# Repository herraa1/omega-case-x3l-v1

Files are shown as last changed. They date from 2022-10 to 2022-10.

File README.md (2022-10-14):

# Omega Home Computer XXXL Acrylic Case

Acrylic case of size XXXL, from now on X3L, for the [Omega Home Computer](https://github.com/skiselev/omega).

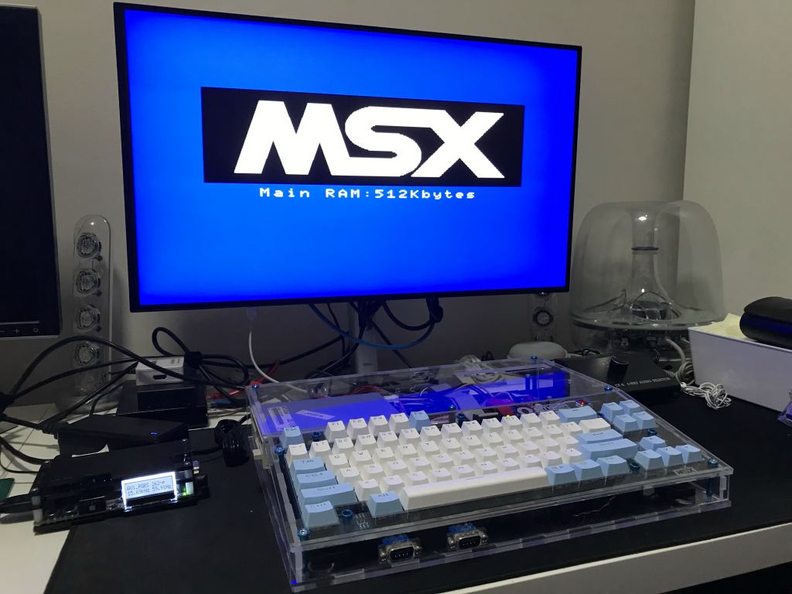
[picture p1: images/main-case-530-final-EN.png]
[](images/main-case-530-final-EN.png)

## Introduction

This is a new acrylic case design[^1] for the Omega Home Computer based on [Capsule5000 XL version](https://github.com/msx-solis/OMEGA-long-case/tree/main/Capsule_XL_current_version), specifically on the Omega-Eco2_SME_51mm_simple_22_09_2021_slot_trasero.dxf design, adding the following extra features:

* the [dc-adapter 1.5-1.6b](https://msxmakers.design.blog/proyectos/omega-home-computer/mini-fuente-dc-dc/) can be installed in the ["inverted-power-barrel"](https://msxmakers.design.blog/proyectos/omega-home-computer/mini-fuente-dc-dc/#barril) configuration without colliding with the floppy disk drive
* the dc-adapter can also be installed in alternate locations using a panel mount power connector (or even the ["anchored-switch"](https://msxmakers.design.blog/proyectos/omega-home-computer/mini-fuente-dc-dc/#anclado) configuration)
* a bigger cutout allows to accomodate the larger rectangular form of the [power SPDT switch 3-pin copper](https://www.aliexpress.com/item/1005001667810183.html) used in the dc-adapter 1.5-1.6b kit
* taller ESR capacitors can be used, with or sans the [multimedia hat](https://msxmakersdesign.files.wordpress.com/2021/09/mmedia_hat_v1.jpg), without colliding with the floppy disk drive
* extra space bellow the floppy disk drive allows a taller and full length heat sink to be installed on top of the VDP if required
* new vent holes below the motherboard VDP footprint are provided for better air flow
* the floppy disk tray is secured to prevent vertical movement irrespective of the floppy disk drive height
* the reset switch has been moved to the keyboard plate, in line with most MSX computers equipped with a reset switch
* all connectors are labeled (using the [MSX font](https://www.msx.org/wiki/MSX_font))[^2]
* the Omega and MSX logos are also incorporated
* (need to be tested) the floppy disk tray has been re-designed trying to remain compatible with the F4/FMPAC v2 hat
* (need to be tested) enough clearance has been kept trying to remain compatible with the O4MEGA v2 hat
* a companion tray has been designed to ease the placement of the dc-adapter 1.5-1.6b (which lacks screw holes on the PCB)

## Dimensions

Dimensions of Capsule5000 XL case

* width  : 360.0 mm
* height :  60.6 mm
* depth  : 287.8 mm

Dimensions of X3L case

* width  : 360.0 mm
* height :  60.6 mm
* depth  : 312.0 mm (+24.2 mm)

## Status

* The case has been built and is fully functional
* The F4/FMPAC v2 compatibility remains untested until a hat is available for testing
* The O4MEGA v2 compatibility remains untested until a hat is available for testing

## Documentation

[Build instructions](Build.md)

[^1]: The case was designed using the [LibreCAD](https://librecad.org/) CAD application.  
[^2]: This [MSX font in TTF format](http://www.ateijelo.com/blog/2016/09/13/making-an-msx-font) was [converted to LFF](https://github.com/LibreCAD/LibreCAD/tree/master/tools/ttf2lff) for use within LibreCAD.

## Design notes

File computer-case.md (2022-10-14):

# Build Instructions for the X3L Computer Case

This document describes how to assemble a X3L case for the Omega Home Computer.

## Bill of Materials (BoM)

### Acrylic parts

#### Computer case (4mm thickness)

The [X3L Computer case](omega-case-x3l-v1-case-with-rear-slot-4mm+ready-to-lasercut-msx-font-normal-final.dxf) for the Omega Home Computer is made up of seven panels:  
* Rear panel (where all the rear connectors are placed)
  * Dimensions: 360.00mm x 60.60mm x 4mm
* Left panel (where the floppy disk drive front is located)
  * Dimensions: 303.95mm x 60.60mm
* Right panel (where the audio/video knobs are attached)
  * Dimensions: 303.95mm x 60.60mm
* Front panel (where the joystick ports are secured)
  * Dimensions: 360.00mm x 28.96mm
* Bottom panel (where the motherboard sits)
  * Dimensions: 360.00mm x 312.00mm
* Top panel (where the top slot is located)
  * Dimensions: 360.00mm x 165.76mm
* Keyboard panel (where the keyboard is attached)
  * Dimensions: 360.00mm x 148.92mm

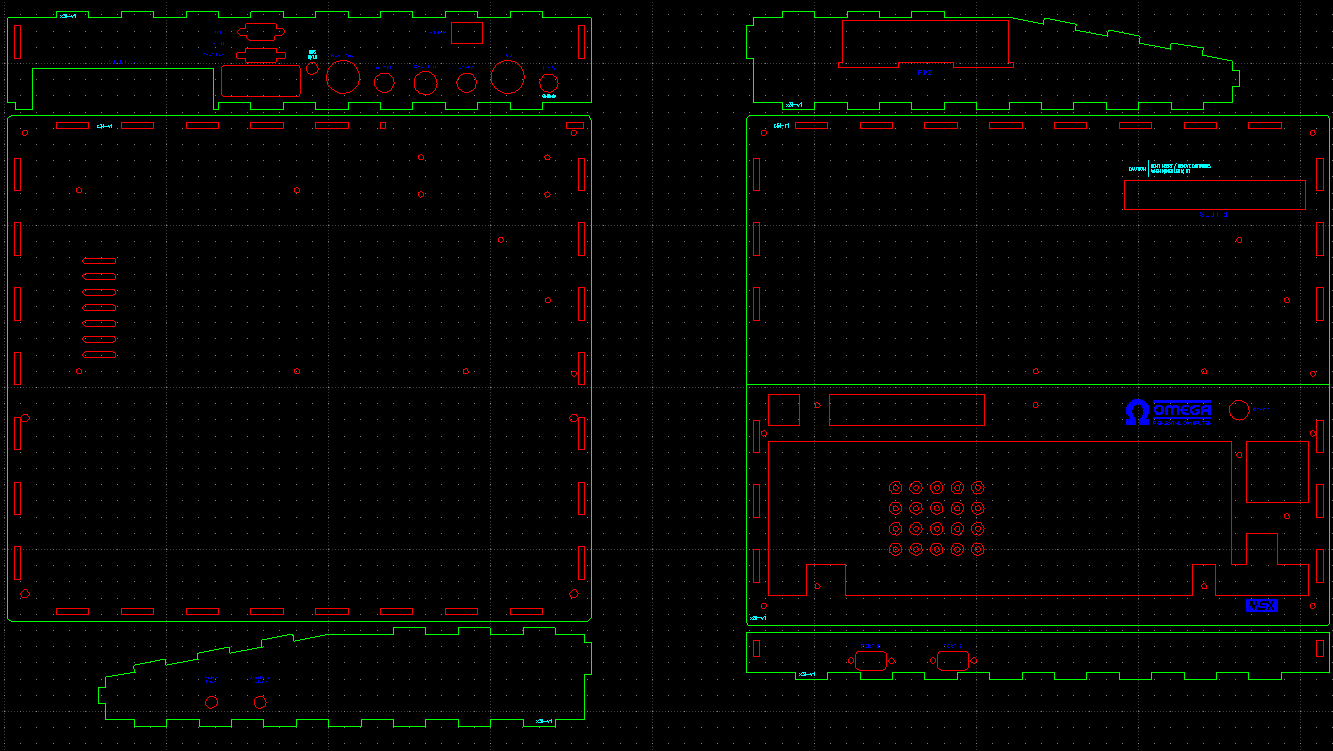
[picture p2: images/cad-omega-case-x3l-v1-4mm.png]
[](images/cad-omega-case-x3l-v1-4mm.png)

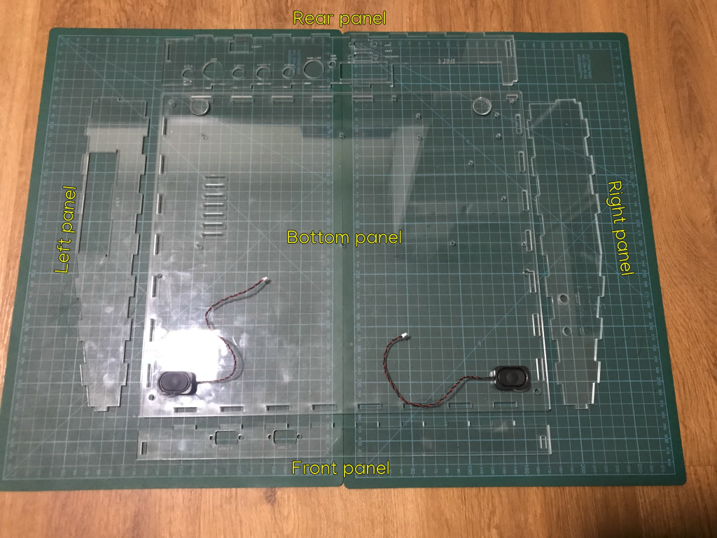
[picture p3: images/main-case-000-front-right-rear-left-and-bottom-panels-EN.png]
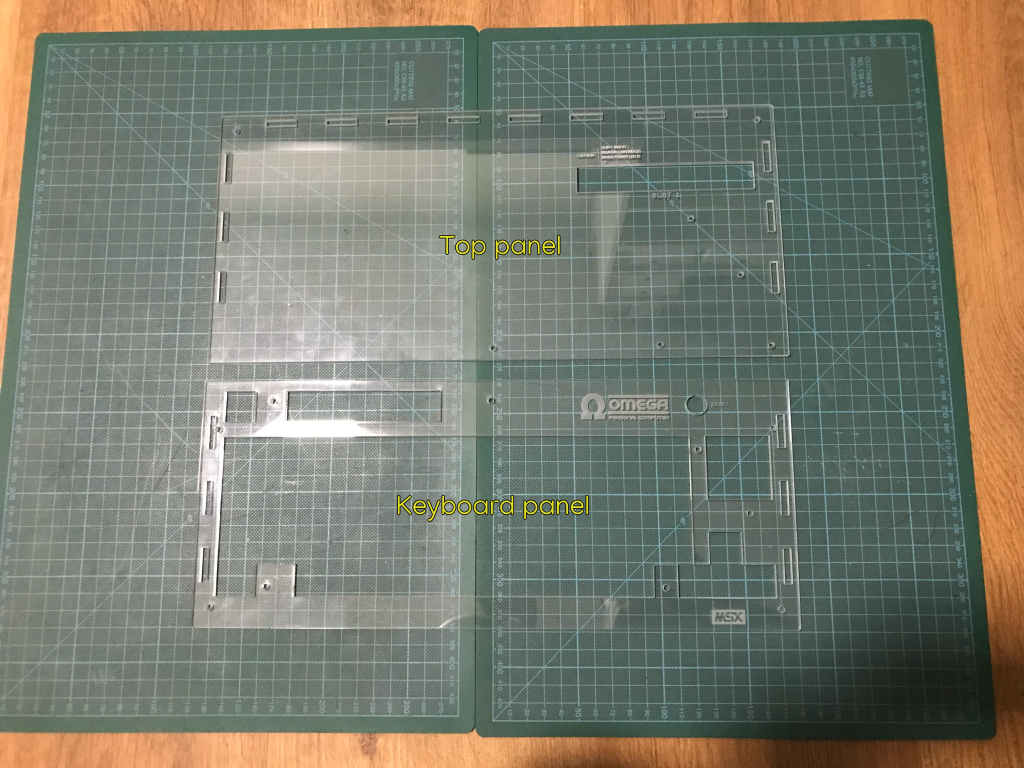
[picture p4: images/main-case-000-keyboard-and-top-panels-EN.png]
[](images/main-case-000-front-right-rear-left-and-bottom-panels-EN.png) [](images/main-case-000-keyboard-and-top-panels-EN.png)

### Laser cutting

The Omega Computer X3L case CAD design requires a 4mm thick acrylic sheet and has 20 layers that must be processed in this order:

| Layer Name | Color | Operation | Required | Comment | Processing Order |
|:---:|---|:---:|---|:---:|:---:|
| engraving-raster | blue  |  engrave  | recommended | Rasterized fonts | 1 |
| engraving-raster-msxlogo | blue  |  engrave  | recommended | MSX logo | 2 |
| engraving-vector | cyan  |  engrave  | recommended | Vectorized fonts | 3 |
| case-top-keyb-int-1 | red | cut | mandatory | internal cuts for spacers | 4 |
| case-top-keyb-int-2 | red | cut | mandatory | external cuts for spacers | 5 |
| case-top-keyb-int-3 | red | cut | mandatory | internal cuts for keyboard plate | 6 |
| *-int (7 layers) | red | cut | mandatory | internal cuts | 7 |
| *-ext (7 layers) | green | cut | mandatory | external cuts | 8 |

### Tools

I used the following tools to build the Omega computer case:

* torx screwdriver (8x60)
* philips screwdriver
* wire stripper & cutter (Stanley FatMax)
* soldering station (Yihua 908D)
* hot air gun
* JST1.25 crimping tool (IWS-2820M)
* XH2.54 crimping tool (SN-01BM)
* Dupont crimping tool (SN-28B)
* Ferrule crimping tool (HSC8 6-4)
* portable drilling machine with countersink 20.5mm drill bit for acrylic

### Mechanical parts

| **item** | **count** | **style** | **material** | **color** | **length (mm)** | **link** |
|---|---|---|---|---|---|---|
| 12mm mini push button switch, momentary, 2 pin | 1 | momentary | metal | red | 12 | [aliexpress](https://www.aliexpress.com/item/32992880809.html) |
| 18AWG silicone wire black | 1 | flexible | silicone,copper | black | 300 | [aliexpress](https://www.aliexpress.com/item/4001048052736.html) |
| 18AWG silicone wire red | 2 | flexible | silicone,copper | red | 300 | [aliexpress](https://www.aliexpress.com/item/4001048052736.html) |
| 20AWG silicone wire black | 1 | flexible | silicone,copper | black | 100 | [aliexpress](https://www.aliexpress.com/item/4001048052736.html) |
| 20AWG silicone wire red | 1 | flexible | silicone,copper | red | 100 | [aliexpress](https://www.aliexpress.com/item/4001048052736.html) |
| 22AWG silicone wire black | 3 | flexible | silicone,copper | black | 400 | [aliexpress](https://www.aliexpress.com/item/4001048052736.html) |
| 22AWG silicone wire blue | 3 | flexible | silicone,copper | blue | 400 | [aliexpress](https://www.aliexpress.com/item/4001048052736.html) |
| 22AWG silicone wire red | 3 | flexible | silicone,copper | red | 400 | [aliexpress](https://www.aliexpress.com/item/4001048052736.html) |
| 22AWG silicone wire yellow | 1 | flexible | silicone,copper | yellow | 400 | [aliexpress](https://www.aliexpress.com/item/4001048052736.html) |
| 24AWG silicone black wire | 1 | flexible | silicone,copper | black | 180 | [aliexpress](https://www.aliexpress.com/item/4001048052736.html) |
| 24AWG silicone blue wire | 1 | flexible | silicone,copper | blue | 350 | [aliexpress](https://www.aliexpress.com/item/4001048052736.html) |
| 24AWG silicone green wire | 1 | flexible | silicone,copper | green | 250 | [aliexpress](https://www.aliexpress.com/item/4001048052736.html) |
| 24AWG silicone red wire | 1 | flexible | silicone,copper | red | 180 | [aliexpress](https://www.aliexpress.com/item/4001048052736.html) |
| 24AWG silicone white wire | 1 | flexible | silicone,copper | white | 600 | [aliexpress](https://www.aliexpress.com/item/4001048052736.html) |
| 26AWG silicone wire black | 1 | flexible | silicone,copper | black | 400 | [aliexpress](https://www.aliexpress.com/item/4001048052736.html) |
| 26AWG silicone wire red | 1 | flexible | silicone,copper | red | 450 | [aliexpress](https://www.aliexpress.com/item/4001048052736.html) |
| 28AWG silicone wire black | 1 | flexible | silicone,copper | black | 250 | [aliexpress](https://www.aliexpress.com/item/4001048052736.html) |
| 28AWG silicone wire black | 1 | flexible | silicone,copper | black | 120 | [aliexpress](https://www.aliexpress.com/item/4001048052736.html) |
| 28AWG silicone wire red | 1 | flexible | silicone,copper | red | 370 | [aliexpress](https://www.aliexpress.com/item/4001048052736.html) |
| 28cm Male jack cable adapter plug 5.5 * 2.1mm 18 AWG | 1 | cable | plastic,copper  | red,black | 280 | [aliexpress](https://www.aliexpress.com/item/4000353876165.html) |
| 4 Ohm 3W mini speakers | 2 | mini | plastic | black | 20 | [aliexpress](https://www.aliexpress.com/item/4001125341633.html) |
| 4-pin floppy power cable 30cm | 1 | 4-pin | plastic,copper  | red,black,yellow | 300 | [aliexpress](https://www.aliexpress.com/item/1005002496348255.html) |
| 5.5mm x 2.1mm DC power jack socket female panel mount barrel connector 11mm | 1 | 5.5x2.1 | metal | metal | 16 | [aliexpress](https://www.aliexpress.com/item/33000366972.html) |
| Blu Tack reusable adhesive putty | 1 | adhesive | putty | blue | 0 | [aliexpress](https://www.aliexpress.com/item/1005004208353049.html) |
| Dupont female pin | 6 | female | copper | metal | 12 | [aliexpress](https://www.aliexpress.com/item/1005001489545874.html) |
| Dupont female sleeve 2-pin | 3 | sleeve | plastic | black | 14 | [aliexpress](https://www.aliexpress.com/item/1005001489545874.html) |
| E0508 bootlace ferrules 0.5mm2 white | 3 | bootlace | plastic,copper  | white | 14 | [aliexpress](https://www.aliexpress.com/item/4000580009797.html) |
| Heat shrink tube black | 1 | tube | plastic | black | 80 | [aliexpress](https://www.aliexpress.com/item/1005004519062414.html) |
| Heat shrink tube blue | 1 | tube | plastic | blue | 20 | [aliexpress](https://www.aliexpress.com/item/1005004519062414.html) |
| Heat shrink tube green | 1 | tube | plastic | blue | 20 | [aliexpress](https://www.aliexpress.com/item/1005004519062414.html) |
| Heat shrink tube red | 1 | tube | plastic | red | 70 | [aliexpress](https://www.aliexpress.com/item/1005004519062414.html) |
| JST 1.25 Male 2-pin plug with wire 15cm 28awg | 2 | male,cable | plastic,copper  | red,black | 150 | [aliexpress](https://www.aliexpress.com/item/4000777530145.html) |
| JST1.25 2-pin male plug | 2 | male | plastic | white | 0 | [aliexpress](https://www.aliexpress.com/item/1005003998299082.html) |
| JST1.25 male pins | 4 | male | copper | metal | 0 | [aliexpress](https://www.aliexpress.com/item/1005003998299082.html) |
| KF2510 8-pin female connector | 1 | 8p,female | plastic | white | 0 | [aliexpress](https://www.aliexpress.com/item/4000229636156.html) |
| KF2510 female pins | 8 | female | copper | metal | 0 | [aliexpress](https://www.aliexpress.com/item/4000229636156.html) |
| M3 4-40 UNC 5/16 inch ~8mm | 8 | pan head, philips | stainless steel | metal | 7.9 | [aliexpress](https://www.aliexpress.com/item/1005003127103343.html) |
| M3 4mm spacers | 11 | round | nylon | white | 4 | [aliexpress](https://www.aliexpress.com/item/33031794972.html) |
| M3 countersunk washer | 34 | countersunk | aluminium | light blue | 2 | [aliexpress](https://www.aliexpress.com/item/32968161596.html) |
| M3 female-female post 10mm | 6 | round | aluminium | light blue | 10 | [aliexpress](https://www.aliexpress.com/item/4000040664908.html) |
| M3 female-female post 16mm | 2 | hex | nylon | black | 16 | [aliexpress](https://www.aliexpress.com/item/1005004311987482.html) |
| M3 female-female post 22mm | 1 | hex | nylon | black | 22 | [aliexpress](https://www.aliexpress.com/item/1005004311987482.html) |
| M3 female-female post 25mm | 4 | round | aluminium | light blue | 25 | [aliexpress](https://www.aliexpress.com/item/4000040664908.html) |
| M3 female-female post 45mm | 5 | round | aluminium | light blue | 45 | [aliexpress](https://www.aliexpress.com/item/4000040664908.html) |
| M3 female-female post 50mm | 3 | round | aluminium | light blue | 50 | [aliexpress](https://www.aliexpress.com/item/4000040664908.html) |
| M3 female-female post 6mm | 5 | hex | nylon | black | 6 | [aliexpress](https://www.aliexpress.com/item/1005004311987482.html) |
| M3 male-female post 20mm+6mm | 1 | hex | nylon | black | 20 | [aliexpress](https://www.aliexpress.com/item/32859166254.html) |
| M3 screw 14mm countersunk | 4 | countersunk, torx | stainless steel | metal | 14 | [aliexpress](https://www.aliexpress.com/item/1005002369233576.html) |
| M3 screw 16mm countersunk | 11 | countersunk, torx | stainless steel | metal | 16 | [aliexpress](https://www.aliexpress.com/item/1005002369233576.html) |
| M3 screw 8mm countersunk | 19 | countersunk, torx | stainless steel | metal | 8 | [aliexpress](https://www.aliexpress.com/item/1005002369233576.html) |
| M3 screw 8mm flat | 6 | flat, torx | stainless steel | metal | 8 | [aliexpress](https://www.aliexpress.com/item/1005003098981878.html) |
| M3 silicone washers | 4 | round | silicone | white | 2 | [aliexpress](https://www.aliexpress.com/item/1005002951669722.html) |
| Machined metal aluminium potentiometer volume knob 20x15mm | 1 | round | aluminium | light blue | 20 | [aliexpress](https://www.aliexpress.com/item/32749281108.html) |
| Mini PAM8403 DC 5V power audio amplifier board | 1 | pcb | n/a | green | 29.5 | [aliexpress](https://www.aliexpress.com/item/1005002116511821.html) |
| Miniature toggle switch red MTS-102 on-on SPST 3-pin | 1 | mini | metal | red | 0 | [aliexpress](https://www.aliexpress.com/item/33032848662.html) |
| Rocker switch KCD1-101 ON-OFF 3-pin SPDT | 1 | 3-pin SPDT | plastic | black | 23.2 | [aliexpress](https://www.aliexpress.com/item/4000054591177.html) |
| XH2.54 2-pin female straight connector | 2 | female-straight | plastic | white | 0 | [aliexpress](https://www.aliexpress.com/item/32871933017.html) |
| XH2.54 2-pin male right angle connector | 1 | right-angle | plastic | white | 0 | [aliexpress](https://www.aliexpress.com/item/32871933017.html) |
| XH2.54 3-pin female straight connector | 1 | female-straight | plastic | white | 0 | [aliexpress](https://www.aliexpress.com/item/32871933017.html) |
| XH2.54 3-pin male right angle connector | 1 | right-angle | plastic | white | 0 | [aliexpress](https://www.aliexpress.com/item/32871933017.html) |
| XH2.54 4-pin female straight connector | 1 | female-straight | plastic | white | 0 | [aliexpress](https://www.aliexpress.com/item/32871933017.html) |
| XH2.54 4-pin male right angle connector | 1 | right-angle | plastic | white | 0 | [aliexpress](https://www.aliexpress.com/item/32871933017.html) |
| XH2.54 female pins | 11 | female | copper | metal | 0 | [aliexpress](https://www.aliexpress.com/item/32871933017.html) |
| XT30 female connector | 1 | female | plastic | yellow | 20.2 | [aliexpress](https://www.aliexpress.com/item/1005003284644920.html) |
| XT30 male connector | 1 | male | plastic | yellow | 20.2 | [aliexpress](https://www.aliexpress.com/item/1005003284644920.html) |

## Step by step instructions

### Keyboard

1. Prepare to attach the keyboard board to the keyboard panel using six posts/spacers

The six posts sit on the keyboard board top side and are fastened via screws on the bottom side. The keyboard panel then sits on top of the posts.  

Place the keyboard board upside down and prepare the following parts:
  * 6x M3 8mm flat torx screws
  * 6x M3 10mm female-female posts

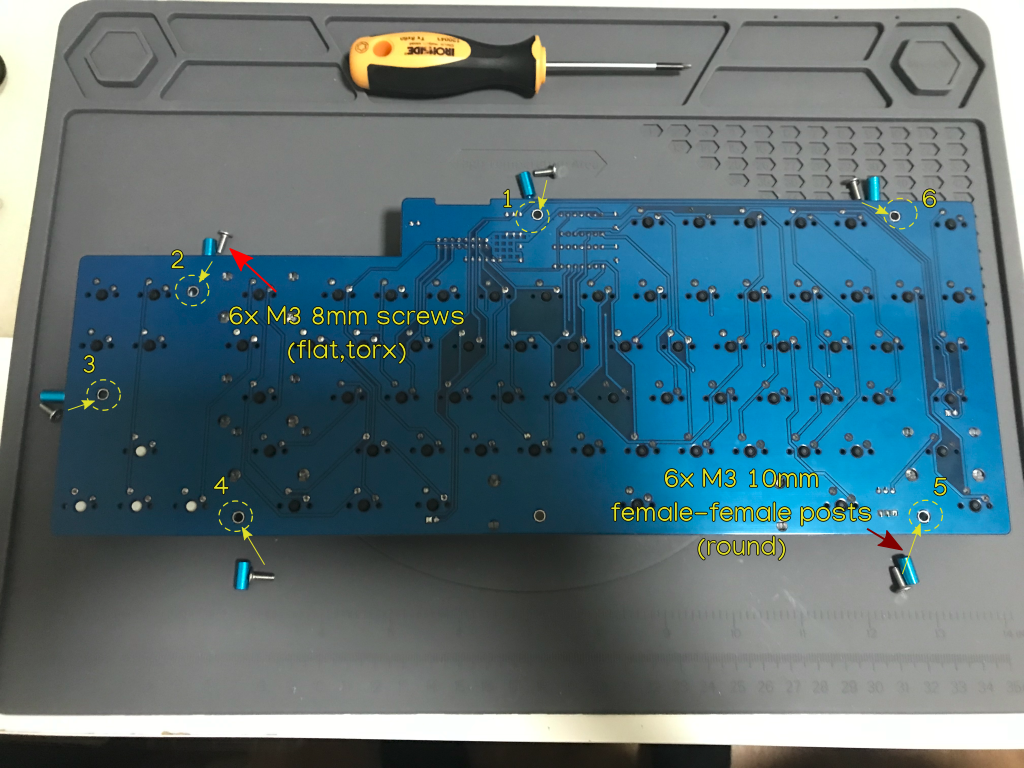
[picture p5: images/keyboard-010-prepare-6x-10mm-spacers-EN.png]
Keyboard: Prepare spacers


2. Fasten the six screws on the keyboard board bottom side to the six posts/spacers on the keyboard board top side

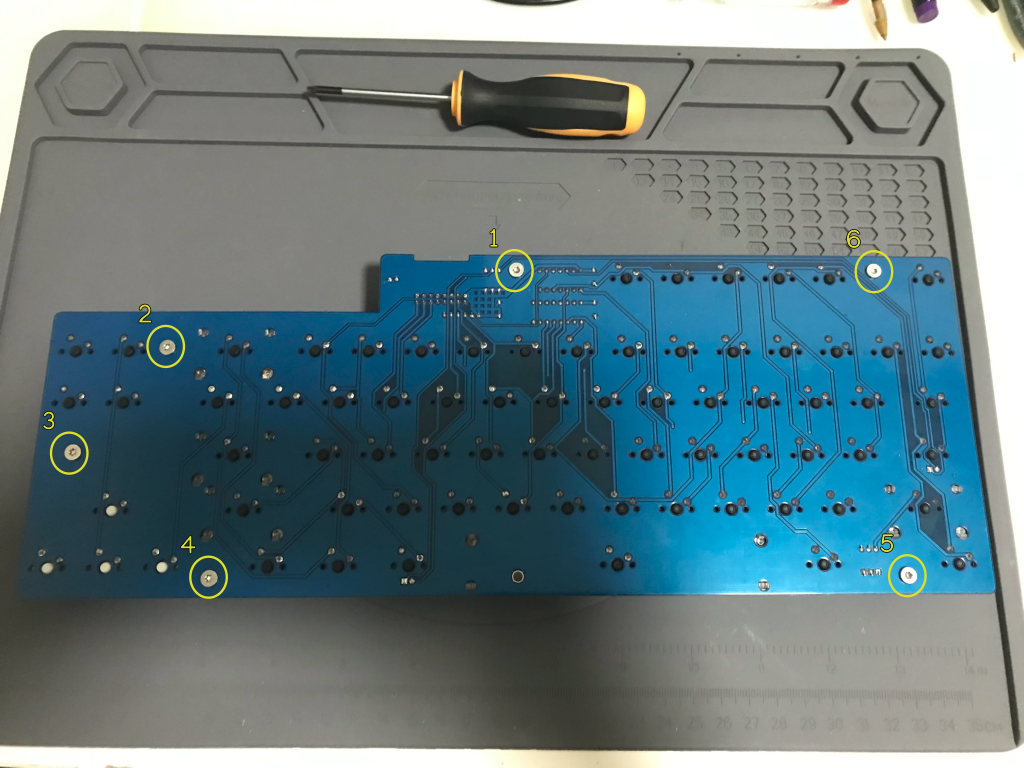
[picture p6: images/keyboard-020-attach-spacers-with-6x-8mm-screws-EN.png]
Keyboard: Attach spacers


3.  Turn the keyboard and check that the posts/spacers are correctly fastened

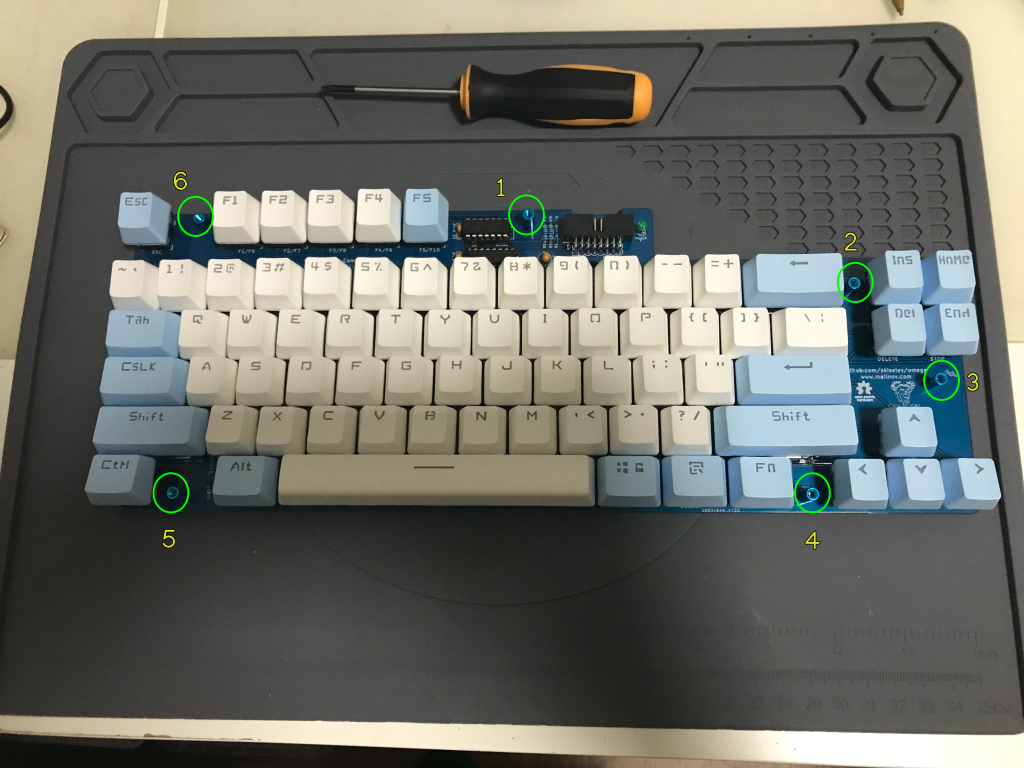
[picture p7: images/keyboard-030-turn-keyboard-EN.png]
Keyboard: Verify spacers


4. Place the keyboard panel on top of the keyboard board and prepare to secure it with six screws in the previously installed spacers

Prepare the following parts:
  * 6x M3 8mm countersunk torx screws
  * 6x M3 countersunk washers

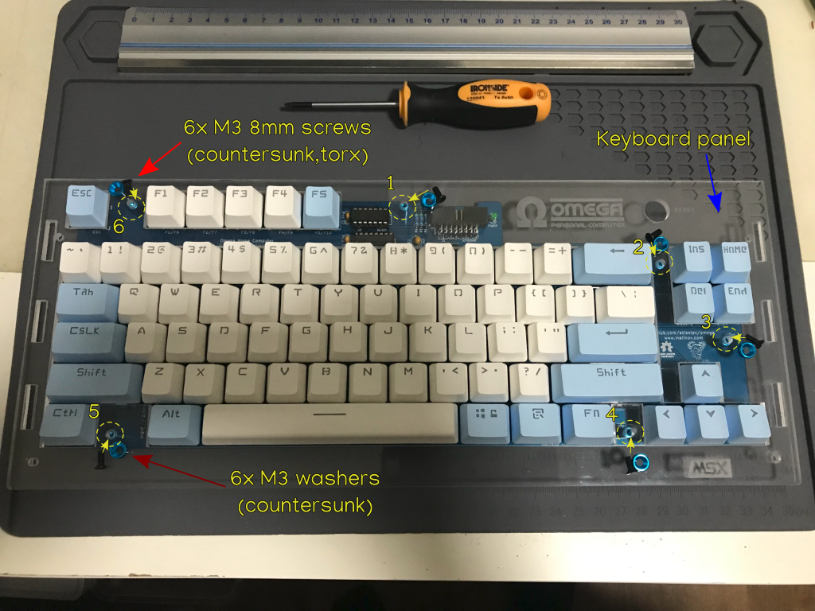
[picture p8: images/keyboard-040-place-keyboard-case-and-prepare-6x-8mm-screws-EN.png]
Keyboard: Add panel and prepare screws


5. Fasten the six screws to attach the keyboard panel to the keyboard board posts/spacers and prepare to install the vertical posts that will secure the keyboard panel to the computer case

Prepare the following parts:
  * 4x M3 8mm countersunk torx screws
  * 4x M3 countersunk washers
  * 2x M3 25mm female-female posts (low half pair, on holes 2 and 3)
  * 2x M3 45mm female-female posts (high half pair, on holes 1 and 4)

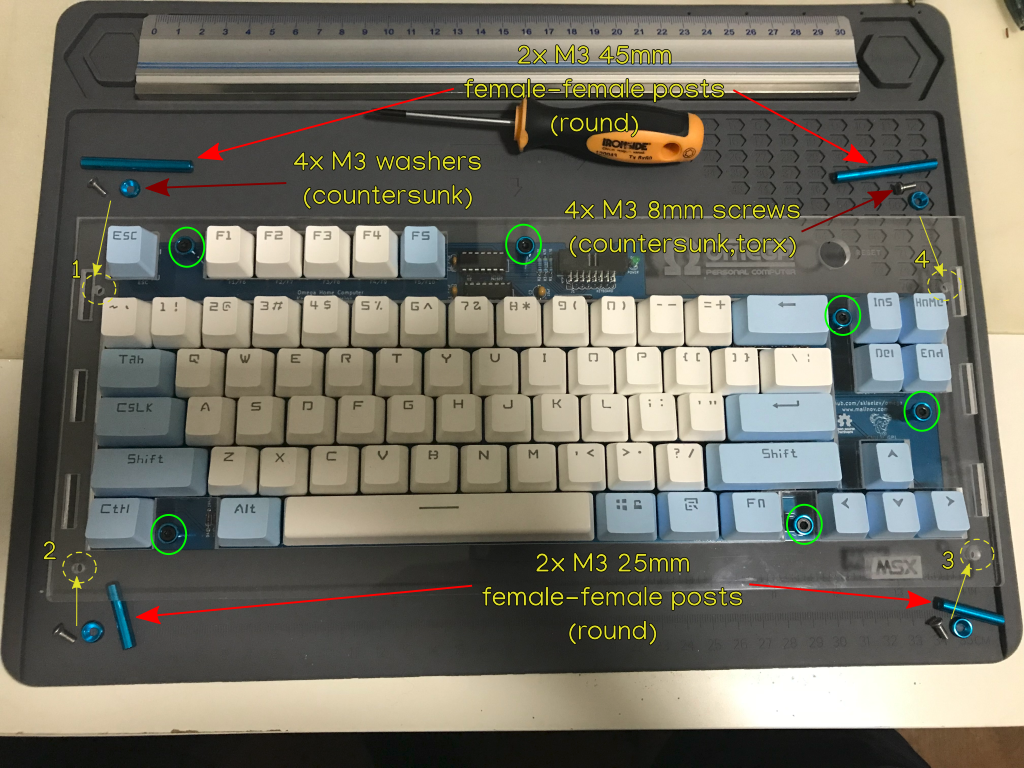
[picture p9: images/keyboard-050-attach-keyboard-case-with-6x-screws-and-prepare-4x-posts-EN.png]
Keyboard: Attach panel and prepare posts


6. Fasten the four screws on the keyboard panel top side to the spacers/posts on the keyboard panel bottom side

The 45mm posts on the high half and the 25mm posts on the bottom half provide a comfortable/ergonomic angled position for the keyboard.

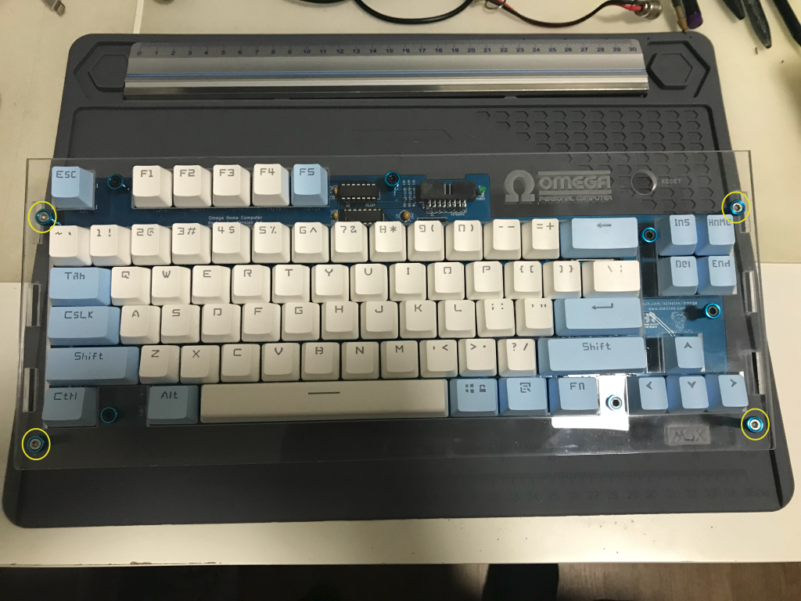
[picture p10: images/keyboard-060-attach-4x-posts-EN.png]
Keyboard: Attach posts


7. Turn the keyboard panel upside down and check that the spacers/posts are correctly fastened

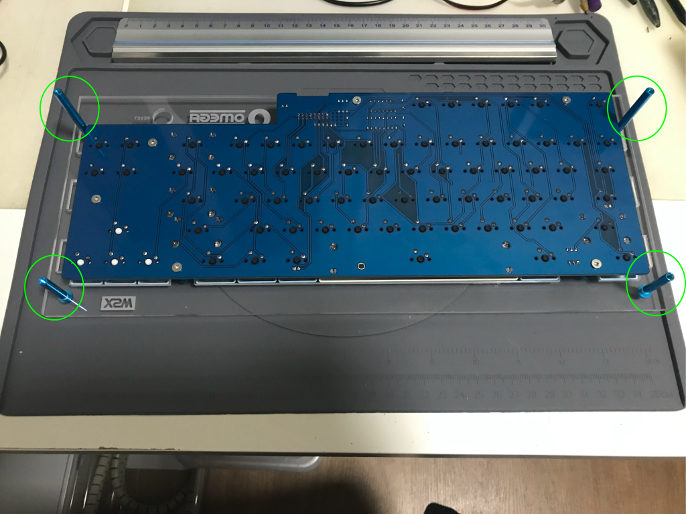
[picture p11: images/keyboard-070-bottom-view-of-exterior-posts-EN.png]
Keyboard: Bottom view


8. Turn the keyboard again and prepare to attach the reset switch to the keyboard panel

The reset switch is a panel mount momentary push switch that attaches via a Dupont two pin female connector to the RST header on the Omega computer motherboard.  
The cable length for the reset switch should be long enough (about 35cm) to allow the keyboard panel to be placed aside the computer without having to disconnect it.

Prepare the following parts:
  * 1x panel mount reset switch
  * about 35 cm of 24 AWG silicone blue wire
  * about 35 cm of 24 AWG silicone white wire
  * 2x Dupont female pin
  * 1x Dupont female sleeve 2p
  * heat shrink tube blue
  * heat shrink tube black

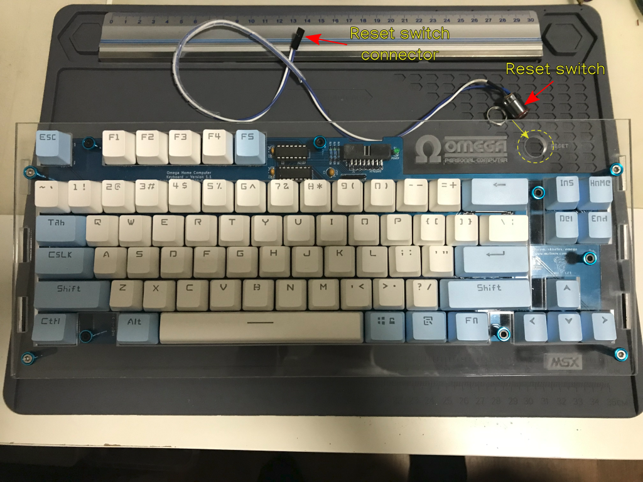
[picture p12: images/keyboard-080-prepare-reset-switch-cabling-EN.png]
Keyboard: Prepare reset switch


9. Attach the reset switch to the keyboard panel reset switch hole

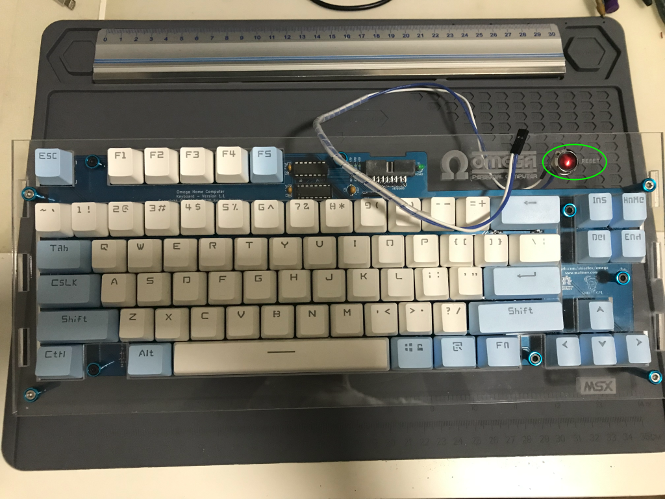
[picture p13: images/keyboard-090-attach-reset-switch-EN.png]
Keyboard: Attach reset switch


### Rest of Computer

1. Place the bottom panel on a work surface and locate the eleven holes needed to secure the motherboard

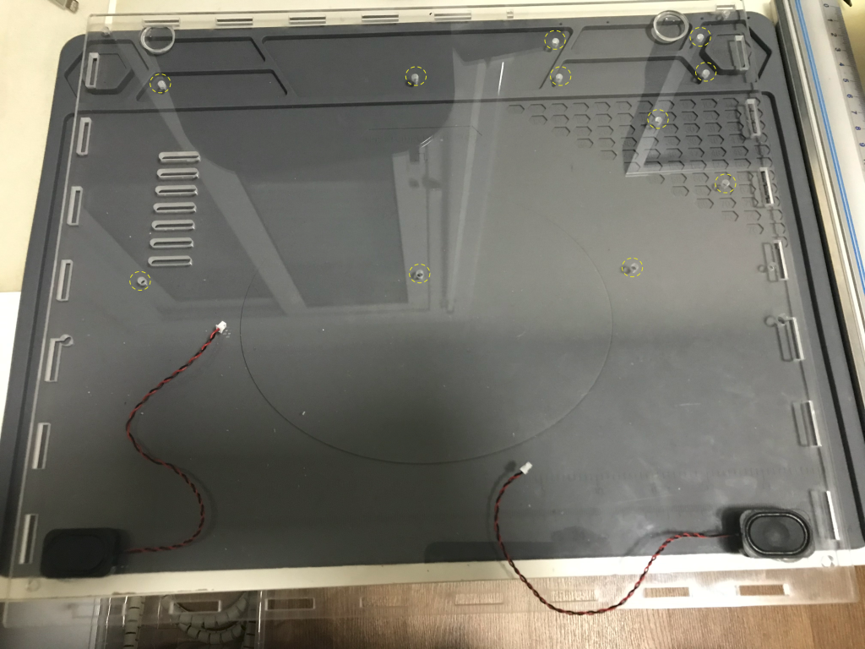
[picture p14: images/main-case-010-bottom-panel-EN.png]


2. Prepare the spacers, washers and screws needed to secure the motherboard to the bottom panel

Prepare the following parts:
  * 11x M3 16mm countersunk torx screws
  * 11x M3 countersunk washers
  * 11x M3 4mm spacers

After laser cutting the keyboard panel you will get 12x 4mm spacers that can be used here, or alternatively you can use 12x 4mm nylon spacers.

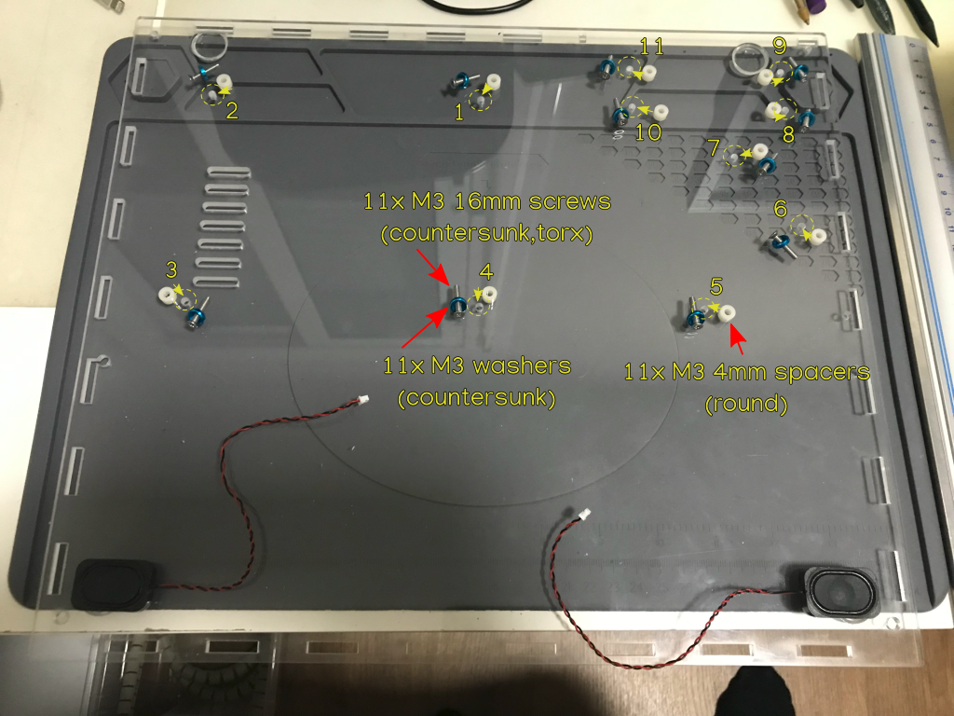
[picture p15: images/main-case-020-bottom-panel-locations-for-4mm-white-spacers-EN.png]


3. Turn the bottom panel and insert (from the bottom side) the screws that will secure the motherboard to the bottom panel

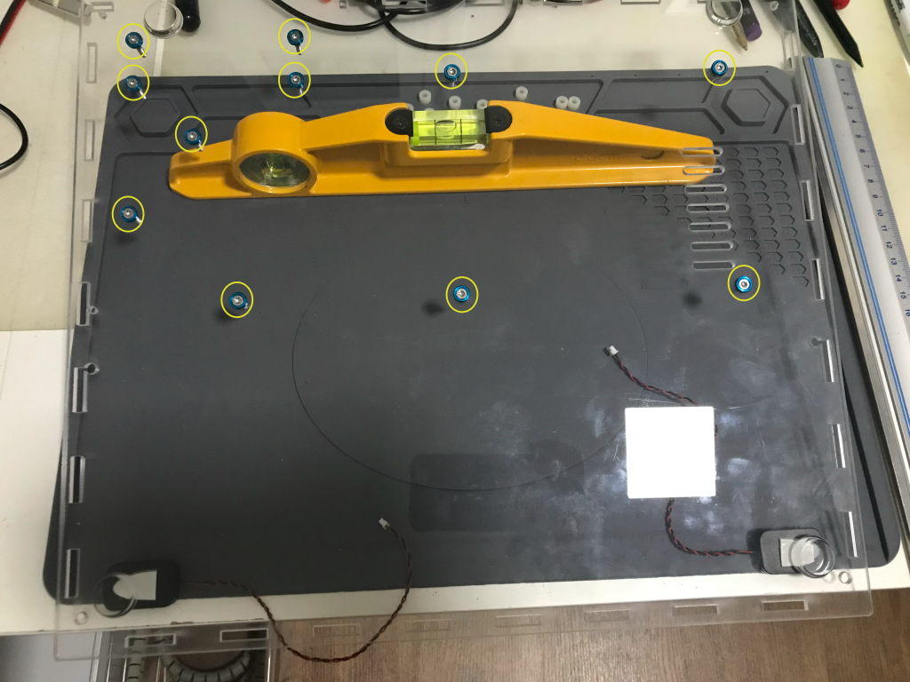
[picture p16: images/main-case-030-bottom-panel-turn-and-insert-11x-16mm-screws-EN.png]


4. Temporarily add Blu-tack on top of the screws to prevent them from falling down when turning again the bottom panel

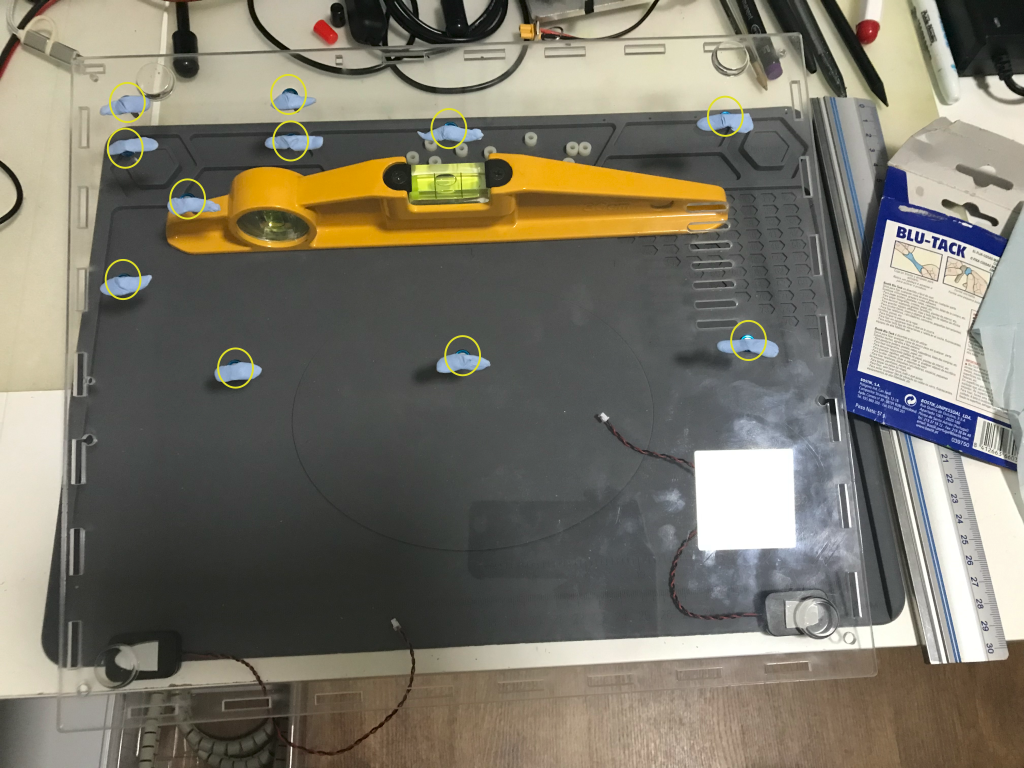
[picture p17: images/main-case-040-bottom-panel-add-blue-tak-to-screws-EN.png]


5. Turn now the bottom panel in preparation for inserting the spacers between the panel and motherboard

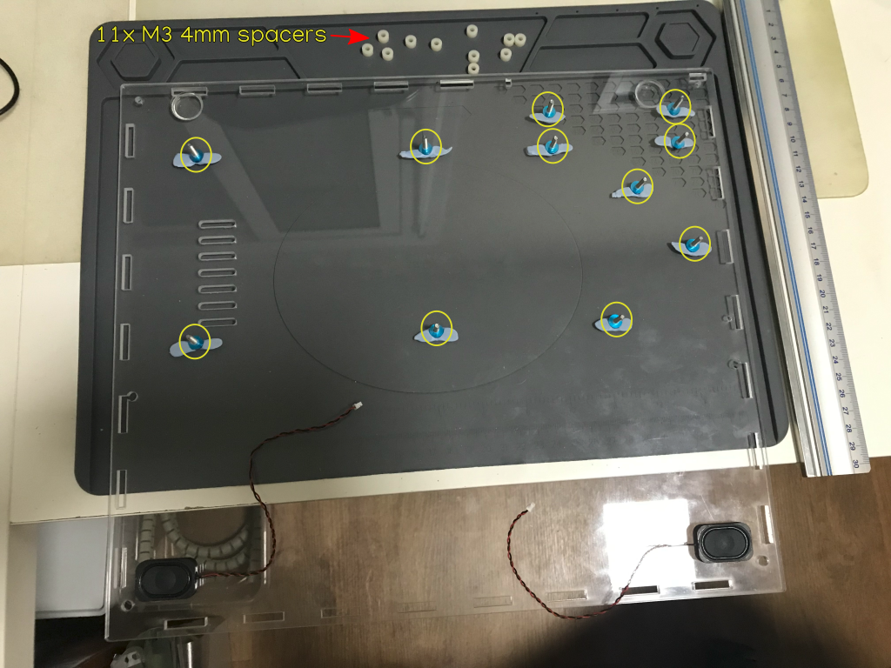
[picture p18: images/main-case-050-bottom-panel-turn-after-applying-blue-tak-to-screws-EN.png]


6. Insert the spacers between the bottom panel and motherboard

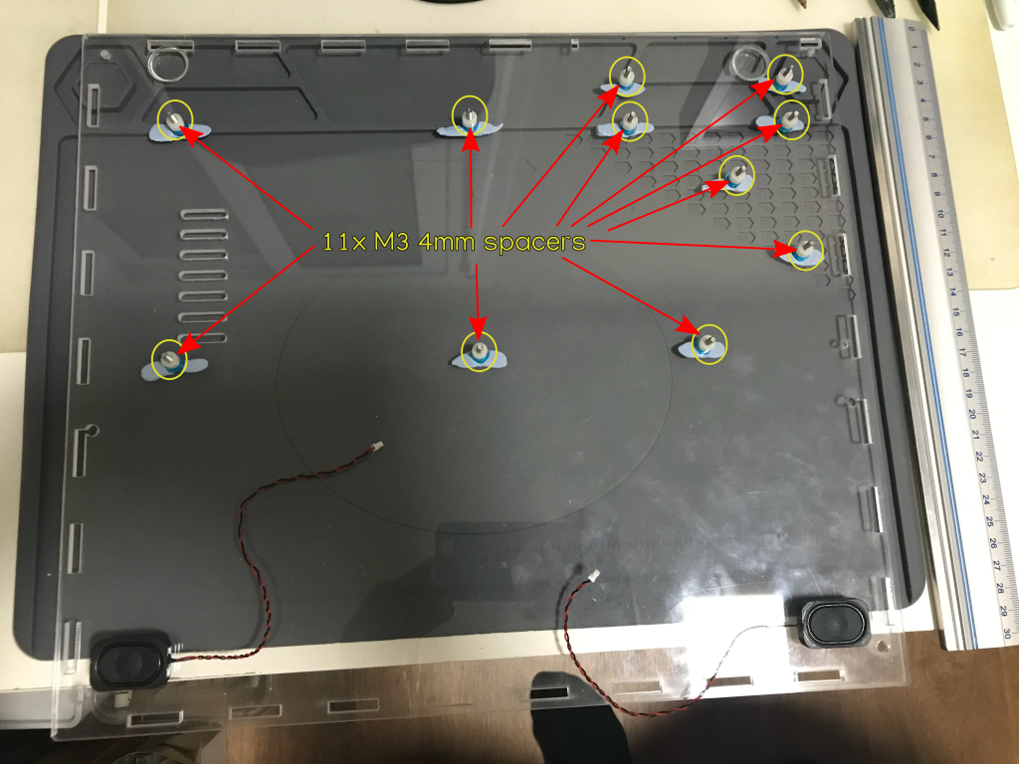
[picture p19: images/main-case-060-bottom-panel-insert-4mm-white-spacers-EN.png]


7. Carefully align the motherboard and slide it down so that it sits on top of the spacers

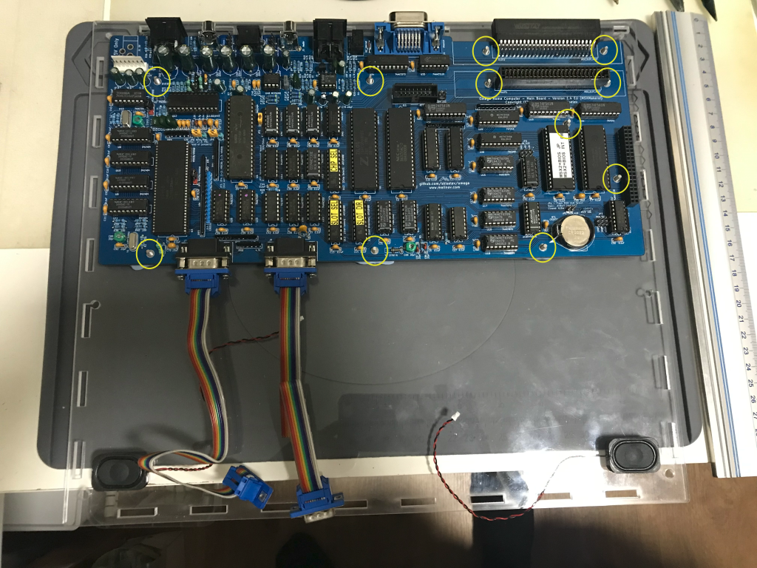
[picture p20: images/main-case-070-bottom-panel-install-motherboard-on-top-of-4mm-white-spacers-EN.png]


8. Add small female-female posts to secure the slot screws and the screw to the right of the motherboard power connector

You will need the following parts:
  * 5x M3 6mm female-female nylon posts

Alternatively, you can use 5x M3 nuts.

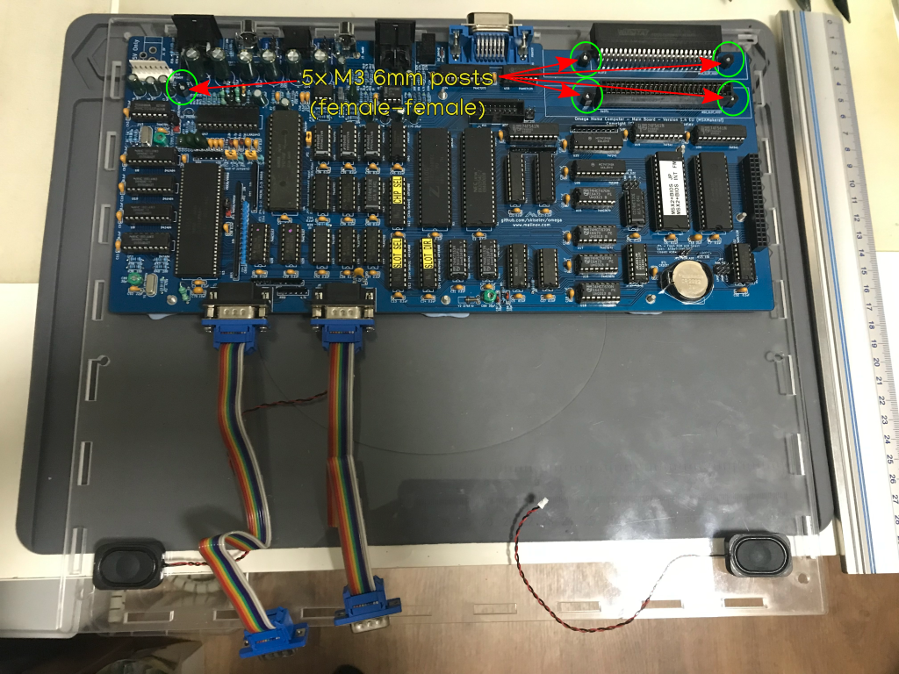
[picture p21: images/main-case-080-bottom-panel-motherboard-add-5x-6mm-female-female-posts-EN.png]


9. Add female-female posts to secure the first two screws related to the floppy tray

You will need the following parts:
  * 2x M3 16mm female-female nylon posts

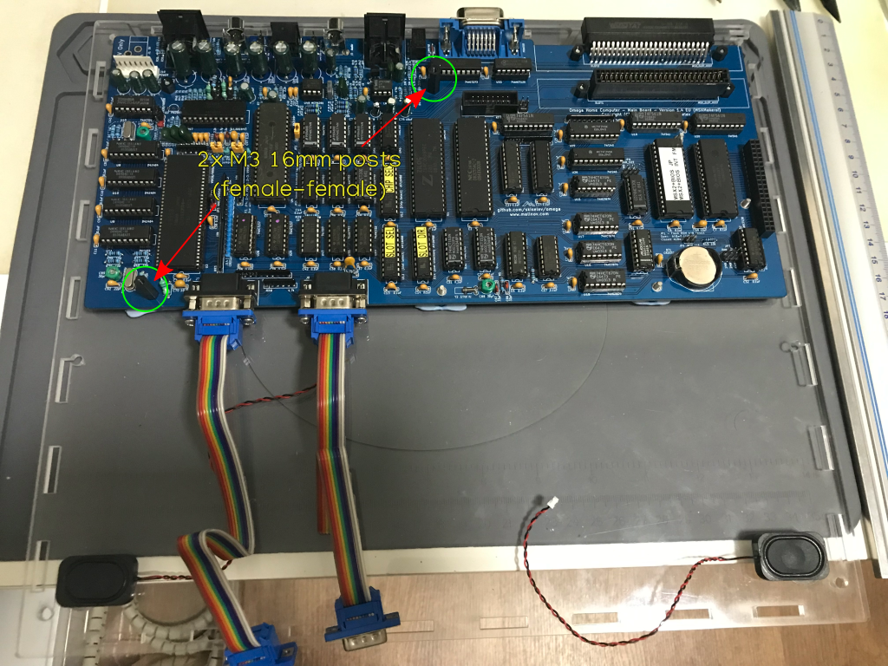
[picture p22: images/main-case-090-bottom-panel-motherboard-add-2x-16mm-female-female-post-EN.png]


10. Add the other female-female post related to the floppy tray and the remaining posts on the right side of the motherboard

You will need the following parts:
  * 1x M3 22mm female-female nylon post
  * 3x M3 45mm female-female aluminium posts

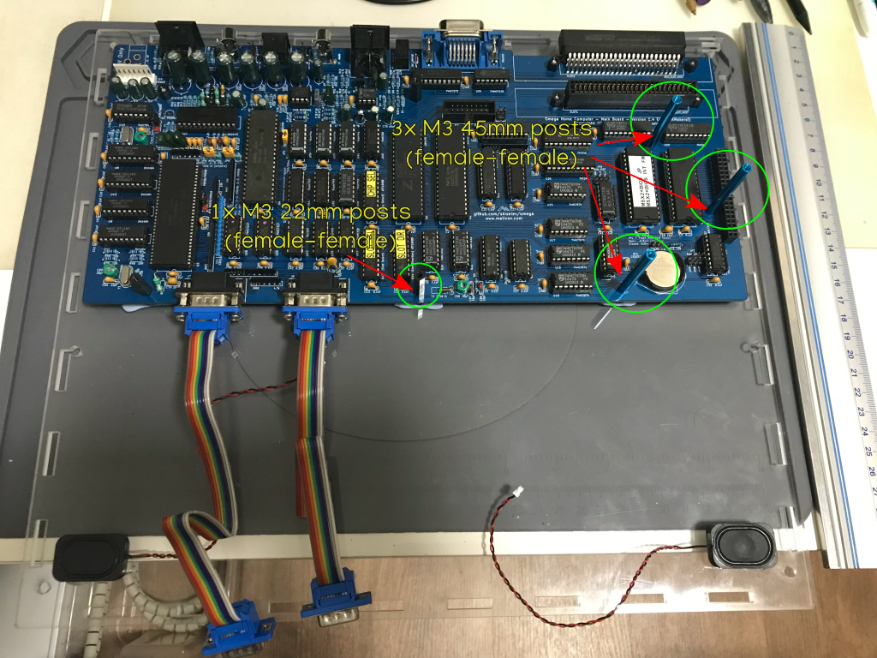
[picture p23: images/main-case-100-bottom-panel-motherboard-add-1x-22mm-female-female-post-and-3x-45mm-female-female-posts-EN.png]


11. Now that the motherboard is completely secured to the bottom panel, turn the bottom panel and prepare to remove the Blu-Tack

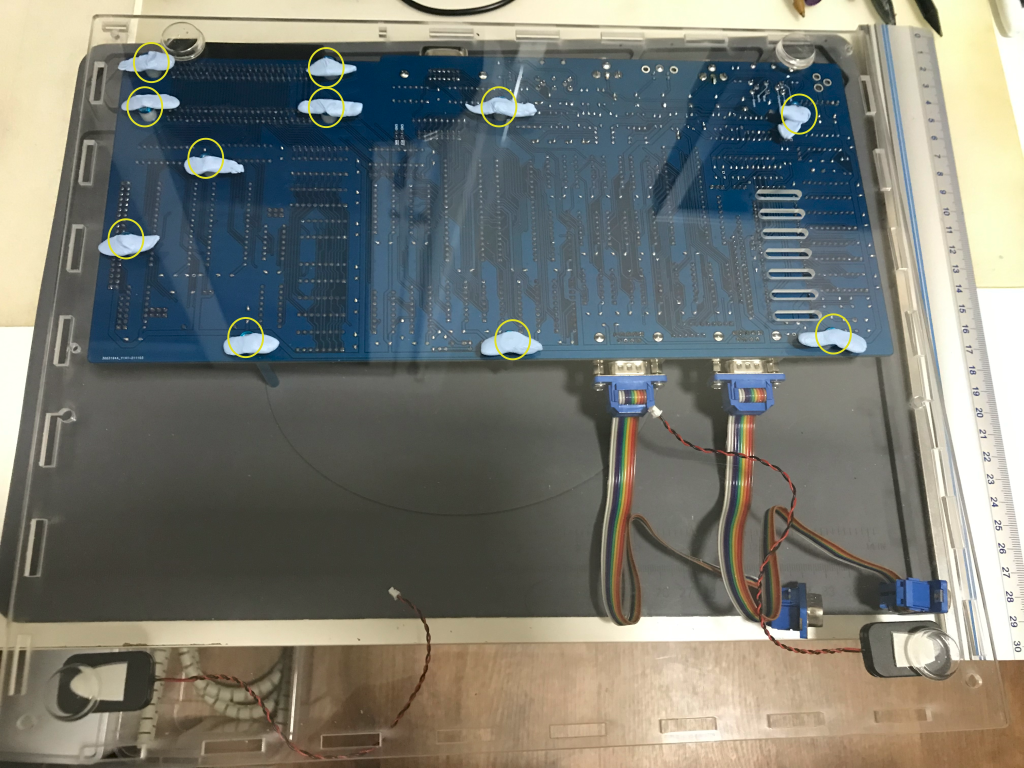
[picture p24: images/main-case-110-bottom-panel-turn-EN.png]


12. Remove the Blu-Tack from the screws on the bottom side of the bottom panel

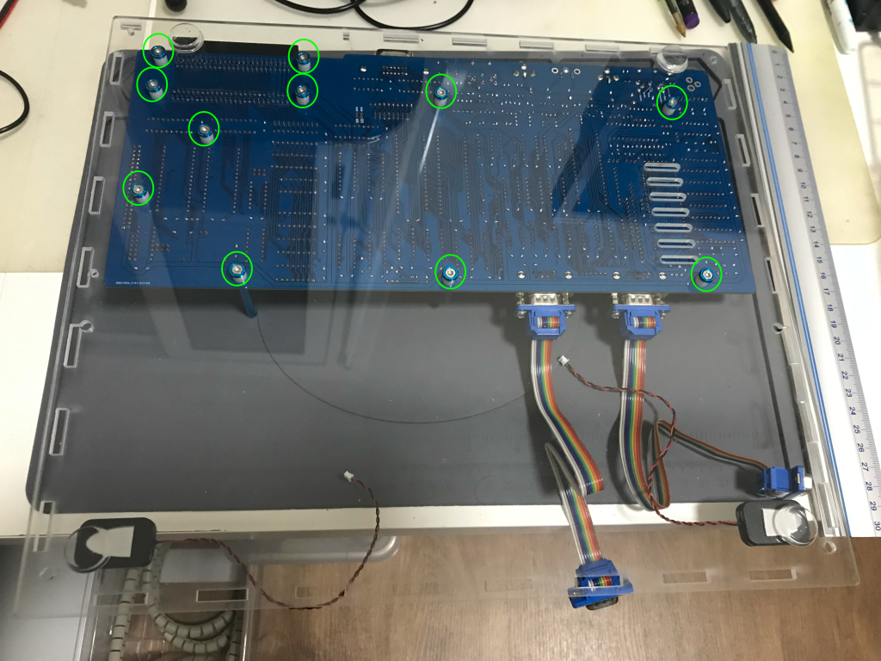
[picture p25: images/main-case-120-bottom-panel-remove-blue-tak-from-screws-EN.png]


13. Turn the bottom panel and prepare to add the posts required to secure the top panel

You will need the following parts:
  * 3x M3 50mm female-female aluminium posts
  * 3x M3 8mm countersunk torx screw
  * 3x M3 countersunk washer



14. Add now the posts that will join the top panel to the bottom panel



15. Install the left, right and rear panels in preparation for the floppy tray insertion



16. Slide the [floppy tray](floppy-tray.md) into the left panel and align the floppy tray arms to the previously installed posts



17. Attach the rear arm of the floppy tray to the matching post using a screw

You will need the following parts:
  * 1x M3 8mm countersunk torx screw
  * 1x M3 countersunk washer



18. Attach the floppy tray wing to the underlying post using a male-female post

You will need the following parts:
  * 1x M3 20mm male-female nylon post



19. Hook the optional audio amplifier board to the right panel

The audio amplifier board is a pre-built DC 5V 3W+3W PAM8403-based board with a potentiometer.  
You will need to solder XH2.54 male right angle connectors to the board connector footprints (rout+lout, power and L+R input) on the bottom side of the board.  

The audio amplifier board is attached to the right panel with the bottom side facing up.  
As the right panel is 4mm thick and the audio amplifier board seems to be prepared for smaller panel thickness, you will need to use a countersunk drill to reduce the thickness of the panel in the speaker volume hole to facilitate the attachment of the audio amplifier.

You will need the following parts:
  * 1x Mini PAM8403 DC 5V power audio amplifier board 2 channel 3W+3W with volume potentiometer
  * 1x XH2.54 4p male right angle connector (rout+lout)
  * 1x XH2.54 2p male right angle connector (power)
  * 1x XH2.54 3p male right angle connector (L+R input)



20. Add a knob to the audio amplifier board potentiometer

You will need the following parts:
  * 1x Machined metal aluminium potentiometer volume knob 20x15mm



21. Install the front panel and connect the speakers to the audio amplifier board

You will need to build a special cable to connect the speakers to the audio amplifier board.  
The audio amplifier board has been fitted with XH2.5 male connectors and the speakers come with JST1.25 female connectors.

You will need the following parts:
  * 1x XH2.54 4p female straight connector
  * 4x XH2.54 female pins
  * about 25cm of 28 AWG wire red (left speaker)
  * about 25cm of 28 AWG wire black (left speaker)
  * about 12cm of 28 AWG wire red (right speaker)
  * about 12cm of 28 AWG wire black (right speaker)
  * 2x JST1.25 2p male plug
  * 4x JST1.25 male pins

Crimping JST1.25 connectors may prove difficult so an alternate option is to buy pre-crimped JST1.25 cables and just crimp the XH2.54 connectors.



22. Prepare to attach the joystick ports extensions to the front panel

You will need the following parts:
  * 4x 4-40 UNC 5/16 inch (~8mm) screws



23. Attach the joystick ports extensions to the front panel



24. Build a DC 5V panel mount barrel connector with cable (if using the dc-adapter in a "panel-mount barrel connector" configuration)

You will need the following parts:
  * 1x 5.5mm x 2.1mm DC power jack socket female panel mount barrel connector 11mm diameter
  * 1x XT30 female connector
  * about 10cm of 20 AWG wire red
  * about 10cm of 20 AWG wire black
  * heat shrink tube red
  * heat shrink tube black

Instead of the XT30 connector you can use any other properly sized and rated connector to decouple the "panel-mount barrel connector" installation from the dc-adapter.  
The size of the connector used must allow the insertion of the washer and nut for the female panel mount barrel connector.  
Another option is to not decouple the installation and to attach directly the female panel mount barrel connector to the dc-adapter, but that makes it difficult to replace the dc-adapter in case of failure or upgrade.



25. Temporarily dismount the rear panel and install the DC 5V panel mount barrel connector in the rear panel



26. Build the BIOS selector panel switch cable

You will need the following parts:
  * 1x miniature toggle switch red MTS-102 on-on SPST 3-pin
  * about 25cm of 24 AWG silicone wire green
  * about 25cm of 24 AWG silicone wire white
  * 1x Dupont female sleeve 2p
  * 2x Dupont female pin
  * heat shrink tube green
  * heat shrink tube black



27. Install the BIOS selector panel switch in the rear panel



28. Mount again the rear panel and connect the BIOS selector cable to the motherboard



29. Prepare the power switch and dc-adapter

Steps 29 to 39 describe how to install the dc-adapter for a "panel-mount barrel connector" configuration.  

Please see the [MSXmakers! dc-adapter page](https://msxmakers.design.blog/proyectos/omega-home-computer/mini-fuente-dc-dc/) for further information about the dc-adapter.

You will need the following parts:
  * dc-adapter 1.5-1.6b populated for your configuration
    * For the "inverted-power-barrel" configuration:
      * (1x DC Power Jack, 2.1mm on J1 bottom side)
      * (1x 8p 2.54 female header on J10 bottom side near the amp meter)
      * 3x 6.3mm spade terminals
      * 1x 20cm of 18 AWG silicone wire black
      * 2x 20cm of 18 AWG silicone wire red
      * 3x E0508 bootlace ferrules 0.5mm2
    * For the "panel-mount barrel connector" configuration
      * 1x KF2510 8-pin female connector
      * 3x 40cm of 22 AWG silicone wire black
      * 3x 40cm of 22 AWG silicone wire red
      * 1x 40cm of 22 AWG silicone wire yellow
      * 1x 40cm of 22 AWG silicone wire blue
      * 3x 6.3mm spade terminals
      * 1x 30cm of 18 AWG silicone wire black
      * 2x 30cm of 18 AWG silicone wire red
      * 3x E0508 bootlace ferrules 0.5mm2
    * For the mixed "inverted-power-barrel" and ""panel-mount barrel connector" configuration:
      * (1x DC Power Jack, 2.1mm on J1 bottom side)
      * (1x 8p 2.54 female header on J10 bottom side near the amp meter)
      * 1x KF2510 8-pin female connector
      * 3x 40cm of 22 AWG silicone wire black
      * 3x 40cm of 22 AWG silicone wire red
      * 1x 40cm of 22 AWG silicone wire yellow
      * 1x 40cm of 22 AWG silicone wire blue
      * 3x 6.3mm spade terminals
      * 1x 30cm of 18 AWG silicone wire black
      * 2x 30cm of 18 AWG silicone wire red
      * 3x E0508 bootlace ferrules 0.5mm2

The mixed "inverted-power-barrel" and ""panel-mount barrel connector" configuration supports any of those configurations.  
When enabling the "panel-mount barrel connector" configuration of the dc-adapter, solder the 8 power cables (on the top side) to the J10 connector which is closer to the XH2.54 power connectors.  

This article describes for now only the "panel-mount barrel connector" configuration, but uses a mixed "inverted-power-barrel" and ""panel-mount barrel connector" dc-adapter build.



30. Connect the step up board to the dc-adapter

The block terminal has 3 terminals:
  * "+5V" (red wire with a "1" marking): connects to the +5V signal from the power supply in the dc-adapter
  * "VCC" (red wire): connects to the VCC signal in the dc-adapter (when the switch is in the ON position the "+5V" and "VCC" terminals are connected together powering the dc-adapter)
  * "DIS" (black wire): connects to the discharge circuit in the dc-adapter (when the switch is in the OFF position the "VCC" and "DIS" terminals are connected together allowing the controlled discharge of the circuit)



31. Prepare the dc-adapter tray

Please, follow the [dc-adapter tray build instructions](dc-adapter-tray.md) to prepare the dc-adapter tray.

32. If not already done, replace the 45mm post near the coin cell battery with a 25mm post to attach the dc-adapter tray

You will need the following parts:
  * 1x M3 25mm female-female aluminium post



33. Install and secure the dc-adapter tray to the Omega computer motherboard via a single post

You will need the following parts:
  * 1x M3 8mm countersunk torx screw
  * 1x M3 countersunk washer



34. Detail of the attachemnt point for the dc-adapter tray



35. Install the power switch in the rear panel, attach the spade terminals to it, and connect the KF2510 connector to the motherboard



36. Detail of the power switch and KF2510 connector

There are 3 spade terminals on the power switch:
  * "+5V" (red with a "1" marking): connects to the +5V signal from the power supply in the dc-adapter
  * "VCC" (red): connects to the VCC signal in the dc-adapter (when the switch is in the ON position the "+5V" and "VCC" terminals are connected together powering the dc-adapter)
  * "DIS" (black): connects to the discharge circuit in the dc-adapter (when the switch is in the OFF position the "VCC" and "DIS" terminals are connected together allowing the controlled discharge of the circuit)



37. Build the cable between the panel mount connector and the dc-adapter

In this case, the cable uses a XT30 male connector to connect to the XT30 female connector on the panel mount barrel connector cable, and a male barrel connector to connect to the dc-adapter female barrel connector in inverse position.  

You will need the following parts:
  * 1x 28cm male jack cable adapter plug 5.5 * 2.1mm 18 AWG (pre-built cable with one end loose)
  * 1x XT30 male connector



38. Install the cable between the panel mount barrel connector cable and the dc-adapter

Connect the cable XT30 male connector to the XT30 female connector on the panel mount barrel connector cable, and the male barrel connector to the dc-adapter female barrel connector.



39. Detail of the cable installation



40. Build the cable to bring the audio signal from the Omega multimedia hat to the audio amplifier board

The cable should be about 40cm long to connect the Omega multimedia hat sound pins to the audio amplifier board audio input connector.  
The end that connects to the Omega multimedia hat is a Dupont 2-pin female connector ("Gnd" and "Sound" signals), and the end that connects to the audio amplifier board input is a XH2.54 3-pin female connector ("L", "G" and "R" signals). The "Sound" signal is duplicated into the "L" and "R" signals to convert the MSX monoaural audio to stereo.

You will need the following parts:
  * 1x Dupont female sleeve 2p
  * 2x Dupont female pin
  * about 40cm of 26 AWG black wire
  * about 40cm of 26 AWG red wire
  * about 5cm extra of 26 AWG red wire (duplicate audio signal)
  * 1x XH2.54 3p female connector
  * 3x XH2.54 female pins
  * heat shrink tube red



41. Connect the audio signal cable between the Omega multimedia hat and the audio amplifier board

Make sure that you align the Dupont connector signals correctly: the black wire needs to connect to the "Gnd" pin on the multimedia hat and the red wire to the "Sound" pin.



42. Detail of the audio signal cable connection on the multimedia HAT



43. Build the audio power cable for the audio amplifier board

The cable should be long enough (in this case about 18cm) to connect the audio amplifier board power connector to the dc-adapter audio power connector.  
Both ends of the cable are XH2.54 2-pin female connectors, but the polarity of the cables is reversed in each end [^1].  

Looking at the connector from the side _without_ pins visible:
  * the dc-adapter side connector (with a "psu" label on the picture) has the GND signal on the _left_ and the +5V signal on the _right_
  * the audio amplifier board side connector (with a "amp" label on the picture) has the GND signal on the _right_ and the +5V signal on the _left_

You will need the following parts:
  * 2x XH2.54 2p female connector
  * 4x XH2.54 female pins
  * about 18cm of 24 AWG silicone black wire
  * about 18cm of 24 AWG silicone red wire

[^1]: As the connectors are polarized and the signals are crossed between the ends, there's no risk of damaging the audio amplifier board even if the wrong end is connected to the wrong board, but the wire colors will not match the expected signals.



44. Connect the power cable to the audio amplifier board

Connect the dc-adapter end of the audio power cable to the dc-adapter audio power connector and the audio amplifier board end to the audio amplifier board power connector.  
Try to not misconnect the audio power cable ends.



45. Add cable sleeves to help routing the cables nicely



46. Connect the keyboard ribbon cable and reset header

If you used a polarized connector for the ribbon cable just align it properly, otherwise make sure that the red stripe of the ribbon cable goes to the left of the connectors looking at the boards from the top.  
The reset header is not polarized so it can be installed either way.



47. Detail of the keyboard connections



48. Align and place the keyboard panel on top of the computer case



49. Connect the floppy power cable

You will need the following parts:
  * 1x 4-pin floppy power cable

Attention must be paid to the orientation of the cable on the dc-adapter side as the pin header is not polarized.  
If you look at the dc-adapter from the top, the floppy power cable should be inserted into the dc-adapter floppy power connector with the connector pins visible on the top.



50. Detail of the floppy power cable connection



51. Place the top panel on top of the computer case and secure it with screws

You will need the following parts:
  * 4x M3 14mm countersunk torx screw
  * 4x M3 countersunk washer

Note that there's a missing screw in the picture ;)



52. Secure the keyboard panel to the bottom panel with screws

Silicone washers are added to account for the inclination of the screws in relation to the bottom panel.

You will need the following parts:
  * 4x M3 8mm countersunk torx screw
  * 4x M3 countersunk washer
  * 4x M3 silicone washers



53. And... enjoy!



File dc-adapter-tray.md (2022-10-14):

# Build Instructions for the dc-adapter tray

This document describes how to assemble the dc-adapter tray for the MSXmakers! dc-adapter power board for the Omega Home Computer.

## Bill of Materials (BoM)

## Acrylic parts

### dc-adapter tray (3mm thickness)

Optional tray for the MSXmakers! dc-adapter 1.5-1.6b.  
This [dc-adapter tray](dc-adaptor-1.6-tray+ready-to-lasercut-final.dxf) can be used to secure the dc-adapter within the computer case when not in the "inverted-power-barrel" or "anchored-switch" configurations.

Dimensions : 64.50mm x 42.67mm x 3mm

[](images/cad-dc-adapter-tray-3mm.png)

## Laser cutting

The dc-adapter tray CAD design has 2 layers that must be processed in this order using a 3mm acrylic sheet:

| Layer Name | Color | Operation | Required  | Comment | Processing Order |
|:---:|---|:---:|---|:---:|:---:|
| INT | red | cut | mandatory | Internal cuts | 1 |
| EXT | green | cut | mandatory | External cuts | 2 |

## Mechanical parts

| **item** | **count** | **style** | **material** | **color**  | **length (mm)** | **link** |
| --- | --- | --- | --- | --- | --- | --- |
| Velcro self fastening tie | 1 | T-type | nylon fabric | red | 150 | [aliexpress](https://www.aliexpress.com/item/1005002179614650.html) |

## Step by step instructions

1. Prepare the dc-adapter tray

You will need the following parts:
  * 1x dc-adapter 1.5-1.6b
  * 1x acrylic dc-adapter tray
  * 1x velcro self fastening tie



2. Add a velcro strip to the dc-adapter tray



3. Place the dc-adapter on the dc-adapter tray and secure it with the velcro strip



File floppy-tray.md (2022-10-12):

# Build Instructions for the floppy tray

This document describes how to assemble the floppy disk drive tray for the Omega Home Computer X3L case.

## Bill of Materials (BoM)

### Acrylic parts

#### Floppy Disk Drive (FDD) tray (3mm thickness)

Tray for the floppy disk drive.  
This tray can be used to attach the floppy disk drive to the computer case.  

The [floppy disk tray](omega-case-x3l-v1-floppy-tray-3mm%2Bready-to-lasercut-final.dxf) is made up of the following elements:
* acrylic floppy tray
* acrylic spacers (12x prepared, but only 2x needed)
* acrylic wing

Dimensions : 179.41mm x 144.46mm x 3mm

[](images/cad-floppy-tray-3mm.png)

### Laser cutting

The floppy disk drive tray CAD design requires a 3mm thick acrylic sheet and has 3 layers that must be processed in this order:

| Layer Name | Color | Operation | Required  | Comment | Processing Order |
|:---:|---|:---:|---|:---:|:---:|
| engraving | blue  |  engrave  | optional  | Contains only versioning label | 1 |
| floppy-tray-int | red | cut | mandatory | Internal cuts | 2 |
| floppy-tray-ext | green | cut | mandatory | External cuts | 3 |

### Mechanical parts

| **item** | **count** | **style** | **material** | **color**  | **length (mm)** | **link** |
| --- | --- | --- | --- | --- | --- | --- |
| M3 nut | 2 | hex | nylon | black | 2 | [aliexpress](https://www.aliexpress.com/item/32859166254.html) |
| M3 screw 14mm countersunk | 2 | countersunk, torx | stainless steel | metal | 14 | [aliexpress](https://www.aliexpress.com/item/1005002369233576.html) |
| M3 screw 8mm flat | 4 | flat, torx | stainless steel | metal | 8 | [aliexpress](https://www.aliexpress.com/item/1005003098981878.html) |
| M3 washer countersunk | 2 | countersunk | aluminium | light blue | 2 | [aliexpress](https://www.aliexpress.com/item/32968161596.html) |

## Step by step instructions

1. Prepare the required material:

  * 1x floppy disk drive

  * 1x acrylic floppy tray (laser cut part)
  * 2x acrylic spacers (laser cut part)
  * 1x acrylic wing (laser cut part)
  * 4x M3 8mm flat torx screws
  * 2x M3 14mm countersunk torx screws
  * 2x M3 countersunk washers
  * 2x M3 nuts

The floppy drive bottom is attached to the floppy tray via four screws.  
Also part of the floppy tray is an elevated wing used to attach the floppy tray to the computer case without colliding with the F4/FMPAC v2 hat. The wing serves aswell as a stop for the keyboard in case excessive force is applied to the keyboard panel top/center.

Prepare floppy tray

2. Turn the floppy drive and acrylic floppy tray upside down and attach the floppy tray to the floppy drive bottom using four M3 8mm flat torx screws

Attach floppy to tray

3. Turn the acrylic floppy tray again so that the floppy is in the normal orientation, and prepare to install the acrylic wing by placing the two acrylic spacers on top of the screw holes in the acrylic floppy tray

Prepare wing

4. Place the acrylic wing on top of the acrylic spacers and attach it using two M3 14mm countersunk torx screws and countersunk washers

Screw wing top

5. Use two M3 nuts on the bottom side to secure the two M3 screws installed on the previous step

Screw wing bottom

6. Once installed, the acrylic wing will look like this as seen from the right side of the floppy disk drive

Floppy tray side view

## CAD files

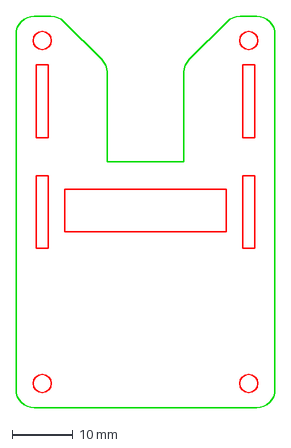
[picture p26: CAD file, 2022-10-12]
dc-adaptor-1.6-tray+ready-to-lasercut-final.dxf
42.7 x 64.5 mm

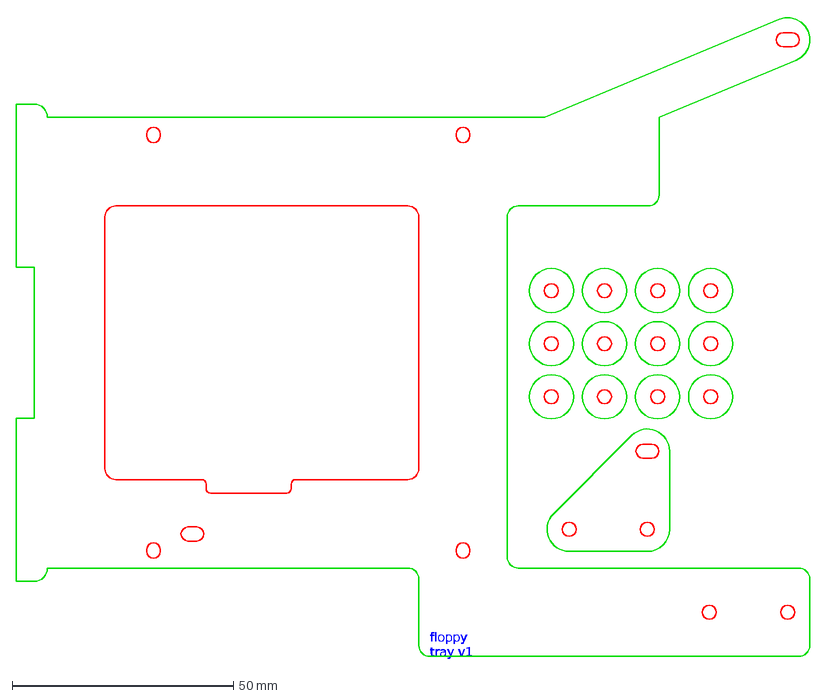
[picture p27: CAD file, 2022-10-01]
omega-case-x3l-v1-floppy-tray-3mm+ready-to-lasercut-final.dxf
floppy tray v1

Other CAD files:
omega-case-x3l-v1-case-with-rear-slot-4mm+ready-to-lasercut-msx-font-normal-final.dxf

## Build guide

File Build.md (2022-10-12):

# Build Instructions

This document describes how to assemble a X3L case for the Omega Home Computer.

## Floppy tray

Begin by building the [floppy tray](floppy-tray.md), it's simple and will get you started.

## dc-adapter tray for MSXmakers! dc-adapter

There are multiple ways of installing the [dc-adapter](https://msxmakers.design.blog/proyectos/omega-home-computer/mini-fuente-dc-dc/) from MSXmakers!.
If you are using a panel mount DC barrel connector configuration, the [dc-adapter tray](dc-adapter-tray.md) will help you attaching the dc-adapter to the computer case.

## Computer case

The rest of the [computer case](computer-case.md) can be built following the provided instructions.

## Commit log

2022-10-01 add floppy tray initial build instructions
    [omega-case-x3l-v1-floppy-tray-3mm+ready-to-lasercut-final.dxf]
2022-10-02 add computer case and incomplete initial build instructions
    [omega-case-x3l-v1-case-with-rear-slot-4mm+ready-to-lasercut-msx-font-normal-final.dxf]
2022-10-12 added missing files for build instructions
    [dc-adaptor-1.6-tray+ready-to-lasercut-final.dxf]
2022-10-14 add computer case picture to readme
2022-10-14 fix length of screw in step 17
2022-10-14 replace wrong XT60 with XT30 connectors
2022-10-14 add mini speakers to the BoM
2022-10-14 fix wrong XT60 connector in pictures
